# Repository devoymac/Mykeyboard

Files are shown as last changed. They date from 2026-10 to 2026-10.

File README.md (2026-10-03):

# Mykeyboard — Split Ergo Keyboard

Teclado ergonómico split de diseño propio. Proyecto de hardware abierto: esquemáticos y PCB en KiCad, firmware en QMK, y carcasa imprimible en 3D.

## Layout

Split columnar-stagger ISO-ES (español completo: Ñ, Ç, ‡, ¡, ¿), ~38 teclas por mitad, espacio dividido y flechas dedicadas.

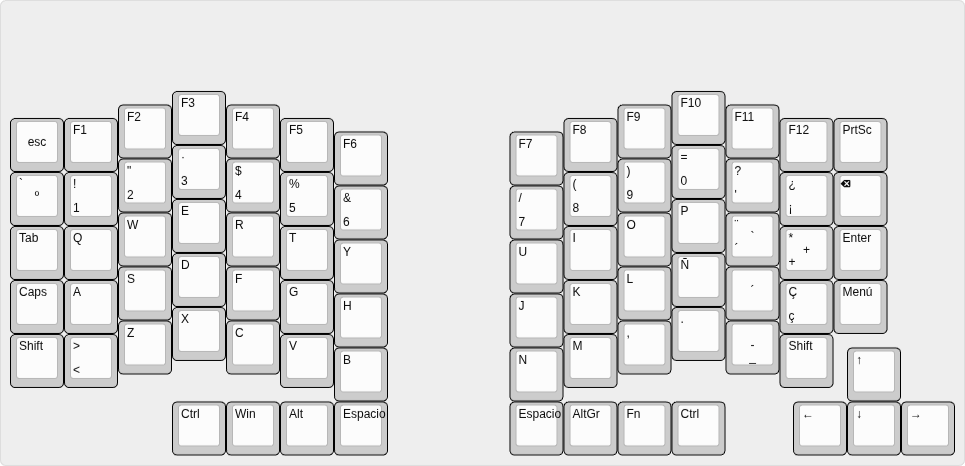
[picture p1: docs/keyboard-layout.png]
Layout del teclado


## Estado

En desarrollo. Estructura del proyecto montada, KiCad 10.0.6 instalado, requisitos y layout definidos.

## Estructura del proyecto

```
Mykeyboard/
├── hardware/          # Diseño electrónico (KiCad)
│   ├── left/          # Mitad izquierda (esquemático + PCB)
│   ├── right/         # Mitad derecha (espejo de la izquierda)
│   └── shared/        # Librerías, símbolos, footprints y plantillas comunes
├── firmware/          # Firmware del teclado (QMK)
├── case/              # Carcasa imprimible en 3D (STL / FreeCAD)
├── docs/              # Documentación: requisitos, layout, BOM, decisiones
├── tools/             # Scripts de utilidad (generación, automatización)
└── README.md
```

## Hardware

- **KiCad**: 10.0.6 (esquemático y PCB).
- **Layout**: split columnar-stagger ISO-ES, ~37-38 teclas por mitad, placa única que se parte en dos (V-cut/mouse bites).
- **Controlador**: RP2040-Zero por mitad, conectadas por TRRS.
- **Switches**: Outemu Silent Lemon V3 (táctiles silenciosos), soldados.
- **Pantalla**: OLED 128x32 (I2C) en la mitad izquierda.
- **Extras**: encoder rotatorio EC11 (volumen/medios) en la mitad derecha.
- Ver [docs/requirements.md](docs/requirements.md), [docs/layout.md](docs/layout.md) y el [BOM](docs/bom.md).

## Firmware

QMK (cableado).

## Cómo contribuir / desarrollo

1. Clona el repositorio.
2. Abre los proyectos de KiCad en `hardware/left` y `hardware/right`.
3. Documenta cualquier cambio relevante en `docs/`.

## Licencia

Pendiente de decidir (recomendado: CERN-OHL-S para hardware, MIT para firmware).

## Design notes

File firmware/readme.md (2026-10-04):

# Mykeyboard

Teclado ergonómico split (cableado) con QMK.

- **Layout:** ISO-ES, 81 teclas (39 izquierda + 42 derecha), columnar stagger
- **MCU:** 2× RP2040-Zero (uno por mitad), comunicación por TRRS
- **Mitad izquierda (master):** OLED 128x32 (I2C)
- **Mitad derecha (slave):** encoder EC11
- **Switches:** Outemu Silent Lemon V3 (soldados)

## Matriz (ambas mitades, misma asignación)

| | GPIO |
|---|---|
| Filas (row 0-5) | GP0, GP1, GP2, GP3, GP4, GP5 |
| Columnas (col 0-6) | GP6, GP7, GP8, GP9, GP10, GP11, GP12 |

## Pines por mitad

**Izquierda (master):**
- OLED: SDA=GP13, SCL=GP14
- TRRS: TX=GP26, RX=GP27

**Derecha (slave):**
- Encoder: A=GP13, B=GP14, SW=GP15
- TRRS: T=GP26, R1=GP27

## Compilar

```sh
qmk compile -kb mykeyboard -km default
```

## Mano (EE_HANDS)

Ambas mitades usan la misma matriz, así que la mano se fija por EEPROM:

```sh
qmk flash -kb mykeyboard -km default -bl uf2-split-left
qmk flash -kb mykeyboard -km default -bl uf2-split-right
```

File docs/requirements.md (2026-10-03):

# Requisitos del teclado

Objetivo: teclado ergonómico split de diseño propio. Requisitos recogidos del usuario (2026-10-02).

## Layout
- Split ergonómico en una sola placa (un solo PCB, un solo controlador por mitad).
- **74 teclas (37 por mitad, simétrico)**, TKL-split: todas las teclas del G513 Carbon menos el numpad. Incluye `/ * - +` (ya en el bloque principal).
- La placa se fabrica de una pieza y se parte en dos mitades (V-cut / mouse bites) tras la fabricación.
- **Navegación y flechas en capas** (PrtSc, ScrLk, Pause, Ins, Home, PgUp, Del, End, PgDn, flechas) — no físicas, se muestran en el OLED.
- Fila de números completa (1-9, 0).
- F1-F12.
- **Layout ISO-ES** completo: Ñ, tilde (´), diéresis (¨), ç/Ç, grave (`), circunflejo (^).
- Pendiente de definir: columnar stagger, thumb clusters, distribución tecla a tecla exacta.

## Teclas imprescindibles
- Tab
- Caps Lock (mayúsculas/minúsculas)
- Shift (izquierdo y derecho)
- Control / Ctrl (izquierdo y derecho)
- Tecla Windows
- Alt y Alt Gr
- Enter
- Borrar (Backspace)
- Flechas (las 4)
- Suprimir (Delete)
- Imprimir pantalla (PrtSc) — para capturas
- Ñ (imprescindible)

## Pantalla / Indicadores
- **OLED 128x32** (I2C) en la **mitad izquierda**. Muestra capa, mayúsculas, WPM, etc.
- Conecta por I2C (GND, VCC, SDA, SCL) — 2 pines GPIO + alimentación.

## Control de medios
- **Encoder rotatorio EC11** en la **mitad derecha**: girar = subir/bajar volumen, pulsar = pausar/continuar, y función "siguiente" (configurable en firmware).
- Conecta al RP2040-Zero por 2 pines (A/B de rotación) + 1 pin (pulsador).

## Conectividad
- **Cableado** (USB). Se descarta inalámbrico/Bluetooth (decisión 2026-10-02).
- **Sin hub USB** (decisión 2026-10-03): el teclado se conecta al PC por un solo USB-C, sin puerto extra para periféricos.

## Hardware elegido
- **Controlador**: RP2040-Zero (Waveshare) por mitad. Cableado, USB-C, 4 MB flash, 20 GPIO.
- **Switches**: Outemu Silent Lemon V3 (táctil silencioso), **soldados** (sin sockets hot-swap).
- **Firmware**: QMK.

## Implicaciones técnicas
- **Layout ISO**: la tecla Ñ define el layout ISO (Enter en forma de L, Ñ junto a la L). Afecta al diseño del PCB y a las keycaps.
- **PrtSc**: poco común en teclados custom; se puede poner como tecla física o en una capa (Fn).
- **Split**: cada mitad lleva su controlador (2 RP2040-Zero), conectadas por TRRS.
- **Sin batería**: al ser cableado, no hay que integrar LiPo ni carga.

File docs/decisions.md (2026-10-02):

# Decisiones de diseño

Registro de decisiones (ADR ligero). Cada entrada: contexto, decisión, alternativas descartadas.

## 2026-10-02 — Inicio del proyecto

- **Decisión**: Estructura del proyecto montada con hardware (KiCad), firmware, case y docs separados.
- **Contexto**: Proyecto nuevo de teclado ergonómico split.
- **Pendiente**: elegir layout, MCU, conexión entre mitades (TRRS vs inalámbrico), y firmware (QMK vs ZMK).

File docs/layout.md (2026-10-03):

# Layout del teclado

74 teclas totales = 37 por mitad (simétrico). Split ISO-ES, placa única que se parte en dos mitades.
El clúster de navegación (PrtSc, ScrLk, Pause, Ins, Home, PgUp, Del, End, PgDn) y las **flechas** van en **capas** y se muestran en el OLED.

## MITAD IZQUIERDA (37 teclas) — Master (RP2040-Zero + OLED + TRRS)

```
Fila F:     F1    F2    F3    F4    F5    F6
Números:    1     2     3     4     5     6
Top:        Q     W     E     R     T
Home:       A     S     D     F     G
Inferior:   Z     X     C     V     B
Modific.:   Tab   Caps  Shift Ctrl  Win   Alt
Pulgar:              [Espacio  AltGr  Fn  Menú]
```

Conteo: F(6) + Números(6) + Top(5) + Home(5) + Inferior(5) + Mod(6) + Pulgar(4) = 37

## MITAD DERECHA (37 teclas) — Slave (RP2040-Zero + encoder + TRRS)

```
Fila F:     F7    F8    F9    F10   F11   F12
Números:    7     8     9     0     -     =
Top:        Y     U     I     O     P
Home:       H     J     K     L     Ñ     ´     ç
Inferior:   N     M     ,     .     /
Modific.:   Enter Bcksp RShift RCtrl Menu  RAlt
Pulgar:              [Espacio   Fn]
```

Conteo: F(6) + Números(6) + Top(5) + Home(7) + Inferior(5) + Mod(6) + Pulgar(2) = 37

## Notas
- La **tilde (´)**, **ç**, **grave (`)**, **circunflejo (^)** y sus variantes Shift van en las teclas ISO-ES de la fila Top/Home derecha.
- El **AltGr** (para €, @, etc.) va en el pulgar o mod izquierdo.
- **PrtSc**, **ScrLk**, **Pause** y multimedia van en una capa FN.
- **Encoder rotatorio EC11** en la mitad derecha (volumen + pausa/continuar + siguiente).
- **OLED** en la mitad izquierda. Cada mitad lleva su RP2040-Zero y jack TRRS.
- El layout incluye el clúster de navegación (PrtSc, ScrLk, Pause, Ins, Home, PgUp, Del, End, PgDn) y las flechas. Sin numpad.

## Matriz (filas × columnas)
- 44 teclas por mitad = matriz de ~6 filas × 7 columnas = 13 pines GPIO por controlador (cabe en los 20 del RP2040-Zero).

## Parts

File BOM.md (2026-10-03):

# Mykeyboard — bill of materials

<!-- Generated by Half Life from project cmuqkjvz601uk01rlczve57yk. Edits here are overwritten on the next sync. -->
<!-- Generated: 2026-10-03T20:49:04.291Z -->

> [!NOTE]
> This parts list is mirrored from [Half Life](https://halflife.hackclub.com). Editing it here will not change the platform's copy, and the next sync overwrites this file.

| Week | Tier | Parts funding |
| --- | --- | --- |
| Warm-up | Tier 1 | $30.00 |

| Part | What it's for | Qty | Unit | Total | Vendor |
| --- | --- | --- | --- | --- | --- |
| [Outemu Silent Lemon V3 (tactile silent)](https://es.aliexpress.com/item/1005007805630498.html) | Switches - quiet tactile for office | 90 | $0.23 | $20.70 | [AliExpress](https://es.aliexpress.com/item/1005007805630498.html) |
| [RP2040-Zero](https://es.aliexpress.com/item/1005008603095009.html) | Microcontroller (one per half) | 2 | $1.74 | $3.48 | [AliExpress](https://es.aliexpress.com/item/1005008603095009.html) |
| [1N4148 diodes SMD (SOD-123)](https://www.aliexpress.com/item/4000470978915.html) | Matrix diodes (one per key) | 100 | $0.01 | $1.00 | [AliExpress](https://www.aliexpress.com/item/4000470978915.html) |
| [OLED 128x32 (0.91in I2C SSD1306)](https://www.aliexpress.com/item/32794209149.html) | Display on left half (I2C) | 1 | $1.12 | $1.12 | [AliExpress](https://www.aliexpress.com/item/32794209149.html) |
| [TRRS audio jack PJ-320A (3.5mm 4-pole)](https://www.aliexpress.com/item/33029465106.html) | Connect the two halves | 10 | $0.16 | $1.60 | [AliExpress](https://www.aliexpress.com/item/33029465106.html) |
| [EC11 rotary encoder (5-pin with push button)](https://www.aliexpress.com/item/32984027505.html) | Knob on right half (volume/media) | 2 | $0.96 | $1.92 | [AliExpress](https://www.aliexpress.com/item/32984027505.html) |
| **Parts subtotal** | — | — | — | **$29.82** | — |
| **Tax & shipping** | — | — | — | **$0.00** | — |
| **Total** | — | — | — | **$29.82** | — |

$0.18 left of the tier's funding.

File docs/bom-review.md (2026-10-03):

# BOM — Under $30 (review copy)

Build total: **~$29.51** (components, before shipping). This is the review version; the importable CSV is `bom.csv`.

## What's in it (in English)

| Item | Qty | Total (USD) | What it's for |
|---|-----|---|---|
| Outemu Silent Lemon V3 (tactile silent) | 90 | $20.37 | The quiet tactile switches you press (85 keys + 5 spare) |
| RP2040-Zero | 2 | $3.49 | Microcontroller — the "brain" of each half |
| 1N4148 diodes (SOD-123) | 100 | $0.97 | One per key, makes the key matrix work |
| OLED 128x32 (I2C SSD1306) | 1 | $1.12 | Screen on the left half (shows layer, caps, etc.) |
| TRRS jack PJ-320A (3.5mm 4-pole) | 10 | $1.64 | Connects the two halves together |
| EC11 rotary encoder (5-pin, push button) | 2 | $1.92 | Knob on right half (volume / play-pause) |
| **TOTAL** | | **$29.51** | |

## How to get it under $30

- Kept the **Outemu Silent Lemon V3** you want, bought **90** (you need 85: 39 left + 46 right).
- Kept all modules (RP2040-Zero, OLED, encoder use their own onboard parts — no extra caps/resistors).

## Link status — please review

- ✅ **RP2040-Zero** and **switches**: I opened these pages directly and verified the price live.
- ⚠️ **Diodes, OLED, TRRS**: links found from search (product IDs from listing databases) — open them to confirm they're live before ordering.
- ⚠️ **EC11 encoder**: link live (HTTP 200), price from a listing database (2 pcs ~$1.92). Open to confirm before ordering. Make sure it's 5-pin with a push button — the user's one at home isn't usable.

## Shipping note

To stay near $30 delivered, prefer sellers with **free shipping** and try to order the switches together with the diodes/jacks from the same store if possible. Separate sellers each add shipping (~$1–3 per order).

> CSV import target: using a generic format so it works in Google Sheets / Excel / Notion etc. Confirm which tool you're importing into if it needs something specific.

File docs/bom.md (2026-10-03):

# BOM — Lista de materiales

Teclado split ergonómico, placa única partida en dos mitades. Cantidades basadas en el layout (~38-45 teclas por mitad).

## Electrónica

> **USB-C**: se usa el puerto del propio RP2040-Zero de la mitad master (no hace falta receptáculo USB-C aparte ni resistencias CC). El cable del PC se enchufa directo al puerto del RP2040-Zero.

| Ref | Componente | Cant. | Notas |
|-----|---|---|---|
| U1, U2 | RP2040-Zero (Waveshare) | 2 | Uno por mitad. |
| SW | Outemu Silent Lemon V3 (táctil silencioso) | ~83 | Según layout; pedir lote de 90 o 110 para repuestos. |
| D1..Dn | Diodo 1N4148 (SMD SOD-123 o DO-35) | ~83 | Uno por tecla (matriz), no incluidas con switches. |
| J | OLED 128x32 (I2C) | 1 | Mitad izquierda. |
| RV1 | Encoder rotatorio EC11 + pulsador | 1 | Mitad derecha (volumen / pausa / siguiente). |
| J1, J2 | Jack audio 3.5mm TRRS (PJ-320A) | 2 | Conectan las mitades. |

> **Sin discretos**: al usar módulos RP2040-Zero (con su propio desacople) y módulos OLED/encoder, no hace falta añadir condensadores ni resistencias externas. Solo si el OLED diera problemas de I2C al probar, añadir 2 pull-ups (4.7kΩ).

## Mecánica / Otros

| Componente | Cant. | Notas |
|---|---|---|
| Cable TRRS 3.5mm | 1 | Une las dos mitades. |
| Cable USB-C | 1 | Al PC. |
| Keycaps | ~83 | Set ISO-ES completo (con Ñ, Ç, etc.). |
| Plate / carcasa (impresa o metal) | 1-2 | Placa superior para los switches. |
| Carcasa 3D (opcional) | 2 | Cases izquierdo/derecho. |
| Tornillos + insertos | ~ | Según carcasa. |

## Estimación de coste (componentes, sin keycaps)

- Controladores: ~4 € (2× RP2040-Zero)
- Switches: ~19 € (lote 90)
- Diodos: ~3 €
- OLED + encoder: ~6 €
- Jacks TRRS: ~2 €
- **Total electrónica: ~34 €** (sin keycaps ni carcasa)

> Las cantidades de teclas son orientativas; cuadrar con el layout definitivo en [docs/layout.md](layout.md).

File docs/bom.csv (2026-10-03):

Item | Qty | Unit Price (USD) | Total (USD) | Vendor | Link | Purpose | Link verified
Outemu Silent Lemon V3 (tactile silent) | 90 | 0.226 | 20.37 | AliExpress | https://es.aliexpress.com/item/1005007805630498.html | Switches - quiet tactile for office | Yes (90pcs = 18.69 EUR)
RP2040-Zero | 2 | 1.74 | 3.49 | AliExpress | https://es.aliexpress.com/item/1005008603095009.html | Microcontroller (one per half) | Yes (1.60 EUR each)
1N4148 diodes SMD (SOD-123) | 100 | 0.010 | 0.97 | AliExpress | https://www.aliexpress.com/item/4000470978915.html | Matrix diodes (one per key) | From search - check
OLED 128x32 (0.91in I2C SSD1306) | 1 | 1.12 | 1.12 | AliExpress | https://www.aliexpress.com/item/32794209149.html | Display on left half (I2C) | From search - check
TRRS audio jack PJ-320A (3.5mm 4-pole) | 10 | 0.164 | 1.64 | AliExpress | https://www.aliexpress.com/item/33029465106.html | Connect the two halves | From search - check
EC11 rotary encoder (5-pin with push button) | 2 | 0.96 | 1.92 | AliExpress | https://www.aliexpress.com/item/32984027505.html | Knob on right half (volume/media) | Live (HTTP 200)
TOTAL |  |  |  | 29.51

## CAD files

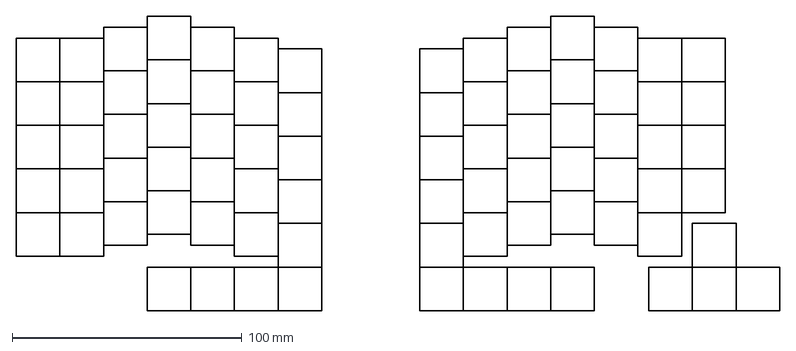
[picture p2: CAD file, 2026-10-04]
docs/demo.dxf
332.5 x 128.2 mm

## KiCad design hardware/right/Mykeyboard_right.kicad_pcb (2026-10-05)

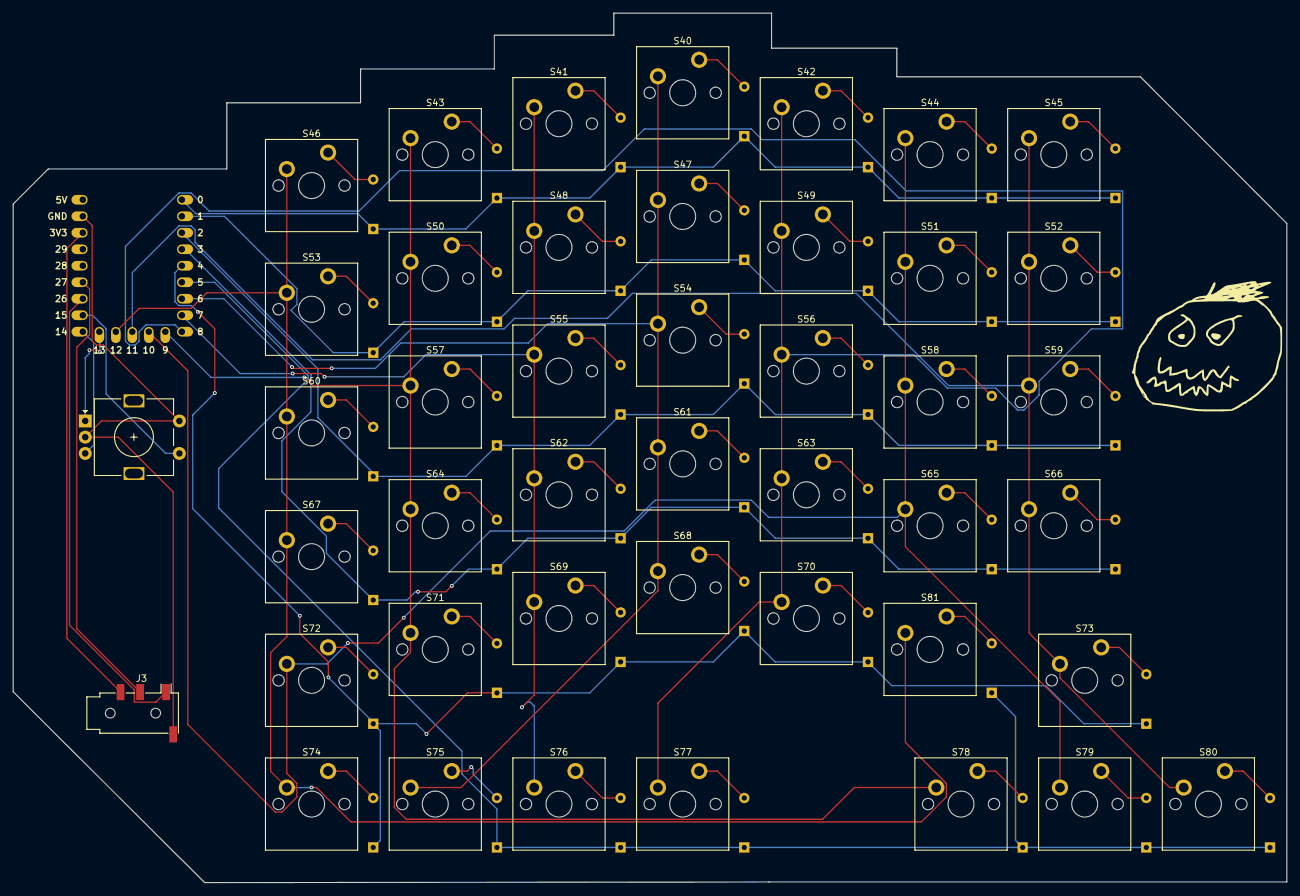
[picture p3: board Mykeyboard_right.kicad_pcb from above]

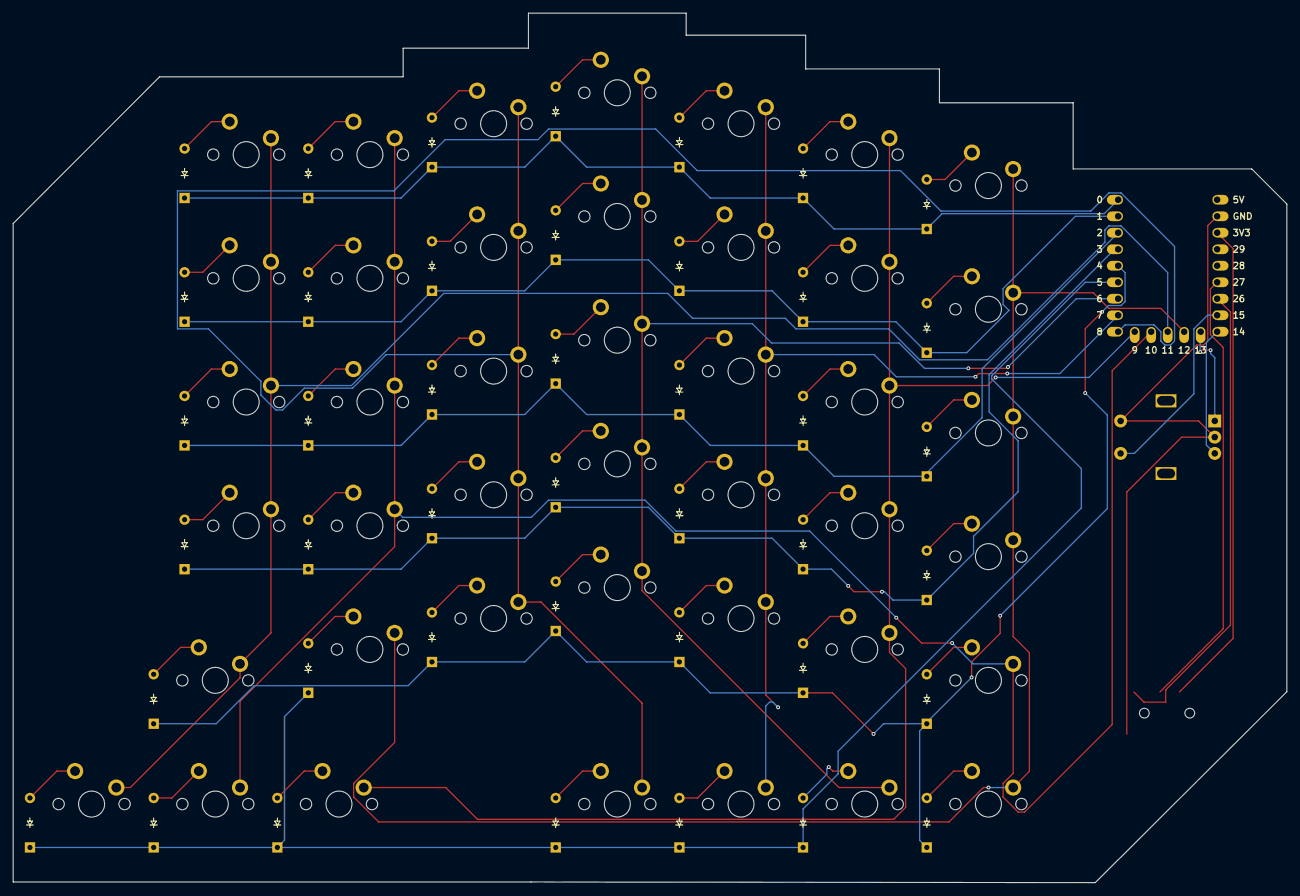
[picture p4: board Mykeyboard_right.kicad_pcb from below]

Board: 2 copper layers, 196.1 x 133.9 mm, 87 parts (42 on the bottom side), 62 nets.

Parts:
D40, D41, D42, D43, D44, D45, D46, D47, D48, D49, D50, D51, D52, D53, D54, D55, D56, D57, D58, D59, D60, D61, D62, D63, D64, D65, D66, D67, D68, D69, D70, D71, D72, D73, D74, D75, D76, D77, D78, D79, D80, D81: Diode_DO-35
J3: AudioJack4; Jack_3.5mm_PJ320D_Horizontal
S40, S41, S42, S43, S44, S45, S46, S47, S48, S49, S50, S51, S52, S53, S54, S55, S56, S57, S58, S59, S60, S61, S62, S63, S64, S65, S66, S67, S68, S69, S70, S71, S72, S73, S74, S75, S76, S77, S78, S79, S80, S81: MX_PCB_1.00u
SW1: RotaryEncoder_Switch; RotaryEncoder_Alps_EC11E-Switch_Vertical_H20mm
U2: RP2040_Zero

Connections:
/colum 7: S40.1, S47.1, S54.1, S61.1, S68.1, S75.1, U2.7 (6)
/colum 8: S41.1, S48.1, S55.1, S62.1, S69.1, S76.1, U2.8 (7)
/colum 9: S42.1, S49.1, S56.1, S63.1, S70.1, S77.1, U2.9 (8)
/colum 10: S43.1, S50.1, S57.1, S64.1, S71.1, S78.1, U2.10 (9)
/colum 11: S44.1, S51.1, S58.1, S65.1, S72.1, S79.1, U2.11 (10)
/colum 12: S45.1, S52.1, S59.1, S66.1, S73.1, S80.1, U2.12 (11)
/colum 13: S46.1, S53.1, S60.1, S67.1, S74.1, S81.1, U2.13 (12)
/row 6: D40.1 (K), D41.1 (K), D42.1 (K), D43.1 (K), D44.1 (K), D45.1 (K), D46.1 (K), U2.1 (0)
/row 7: D47.1 (K), D48.1 (K), D49.1 (K), D50.1 (K), D51.1 (K), D52.1 (K), D53.1 (K), U2.2 (1)
/row 8: D54.1 (K), D55.1 (K), D56.1 (K), D57.1 (K), D58.1 (K), D59.1 (K), D60.1 (K), U2.3 (2)
/row 9: D61.1 (K), D62.1 (K), D63.1 (K), D64.1 (K), D65.1 (K), D66.1 (K), D67.1 (K), U2.4 (3)
/row 10: D68.1 (K), D69.1 (K), D70.1 (K), D71.1 (K), D72.1 (K), D73.1 (K), D74.1 (K), U2.5 (4)
/row 11: D75.1 (K), D76.1 (K), D77.1 (K), D78.1 (K), D79.1 (K), D80.1 (K), D81.1 (K), U2.6 (5)
unnamed: D40.2 (A), S40.2
unnamed: D41.2 (A), S41.2
unnamed: D42.2 (A), S42.2
unnamed: D43.2 (A), S43.2
unnamed: D44.2 (A), S44.2
unnamed: D45.2 (A), S45.2
unnamed: D46.2 (A), S46.2
unnamed: D47.2 (A), S47.2
unnamed: D48.2 (A), S48.2
unnamed: D49.2 (A), S49.2
unnamed: D50.2 (A), S50.2
unnamed: D51.2 (A), S51.2
unnamed: D52.2 (A), S52.2
unnamed: D53.2 (A), S53.2
unnamed: D54.2 (A), S54.2
unnamed: D55.2 (A), S55.2
unnamed: D56.2 (A), S56.2
unnamed: D57.2 (A), S57.2
unnamed: D58.2 (A), S58.2
unnamed: D59.2 (A), S59.2
unnamed: D60.2 (A), S60.2
unnamed: D61.2 (A), S61.2
unnamed: D62.2 (A), S62.2
unnamed: D63.2 (A), S63.2
unnamed: D64.2 (A), S64.2
unnamed: D65.2 (A), S65.2
unnamed: D66.2 (A), S66.2
unnamed: D67.2 (A), S67.2
unnamed: D68.2 (A), S68.2
unnamed: D69.2 (A), S69.2
unnamed: D70.2 (A), S70.2
unnamed: D71.2 (A), S71.2
unnamed: D72.2 (A), S72.2
unnamed: D73.2 (A), S73.2
unnamed: D74.2 (A), S74.2
unnamed: D75.2 (A), S75.2
unnamed: D76.2 (A), S76.2
unnamed: D77.2 (A), S77.2
unnamed: D78.2 (A), S78.2
unnamed: D79.2 (A), S79.2
unnamed: D80.2 (A), S80.2
unnamed: D81.2 (A), S81.2
unnamed: J3.R2, U2.21 (3V3)
unnamed: SW1.A, U2.14 (13)
unnamed: SW1.B, U2.15 (14)
unnamed: SW1.S1, U2.16 (15)
unnamed: J3.T, U2.17 (26)
unnamed: J3.R1, U2.18 (27)
unnamed: J3.S, SW1.C, SW1.S2, U2.22 (GND)

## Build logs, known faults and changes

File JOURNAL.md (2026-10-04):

# Mykeyboard — devlog

<!-- Generated by Half Life from project cmuqkjvz601uk01rlczve57yk. Edits here are overwritten on the next sync. -->
<!-- Generated: 2026-10-04T21:28:46.204Z -->

> [!NOTE]
> This devlog is mirrored from [Half Life](https://halflife.hackclub.com). Editing it here will not change the platform's copy, and the next sync overwrites this file.

> An ergonomic keyboard for daily use

| Week | Tier | Hours logged | Entries |
| --- | --- | --- | --- |
| Warm-up | Tier 1 | 10h | 3 |

## Contents

1. [2026-10-03 — My split ergo keyboard p](#2026-10-03-imagehttpshalflifehackclub-assetscomhackclub-half)
2. [2026-10-04 — Hit a wall today, but figured it out. Turns out the layout I had originally was misplaced — the columns weren't lined up right, so it wasn't actually symmetric after all. That bugged me, so I redid th](#2026-10-04-hit-a-wall-today-but-figured-it-out-turns-out-the)
3. [2026-10-04 — In the end I decided to do it as two separate boards and then join them together. It took me a while to decide, but it makes total sense: each half with its own RP2040-Zero, and the two talk to each o](#2026-10-04-in-the-end-i-decided-to-do-it-as-two-separate-boa)

## Design

### 2026-10-03 — My split ergo keyboard p

**3h**

My split ergo keyboard project — how it's going

KiCad and the libraries

I set up KiCad 10.0.6 and realized I was missing the kicad-library package — the one that ships all the symbols and footprints. That's why I kept getting that "library table not found" error when I opened the libraries window. Once I installed it, everything clicked into place.

I also grabbed the ScottoKicad library (Joe Scotto's, the go-to for handwired keyboards)

Nailing down what I want

I figured out the design as I went and jotted it down in docs/requirements.md:

- Wired (USB), no wireless.
- Spanish ISO layout: Ñ, accent marks, ç/Ç, ¡, ¿, the whole set.
- No numpad (don't use it).
- One single PCB that I split into two halves afterwards (V-cut / mouse bites) so I only order one board from JLCPCB.
- 37+37 keys, symmetric.
- OLED 128x32 on the left + EC11 encoder on the right.
- 2× RP2040-Zero, using the USB-C that already comes on the board itself (no hubs or extra receptacles).

Hunting down components

- 90 switches Outemu Silent Lemon V3 (silent tactile, so I don't annoy everyone at home)
- 2 RP2040-Zero.
- OLED, encoder, TRRS jacks

The layout in KLE

I ended up designing the layout to my liking in Keyboard Layout Editor:

My layout


It's a split columnar-stagger in Spanish, ~37–45 keys per half, split spacebar, thumb clusters, and dedicated arrows on the right. Pretty happy with how it turned out.

The BOM and the repo

- Put together the BOM (docs/bom.md) with the full part list: ~€34 of electronics.
- Updated the README with the layout image and where the project stands.

My whole project is actually inspired by my main keyboard, the Logitech G513 Carbon — I've been using it for ages and it works great. But I wanted to take a simple step toward this new kind of keyboard, the ergonomic split, without leaving everything else behind.



### 2026-10-04 — Hit a wall today, but figured it out. Turns out the layout I had originally was misplaced — the columns weren't lined up right, so it wasn't actually symmetric after all. That bugged me, so I redid th

**4h**

Hit a wall today, but figured it out. Turns out the layout I had originally was misplaced — the columns weren't lined up right, so it wasn't actually symmetric after all. That bugged me, so I redid the whole thing from scratch.
And I actually got the whole schematic done! Switches + diodes matrix, both halves wired, the RP2040-Zero(s), the OLED, the TRRS jacks, and the encoder all placed and connected. Fixed the footprints as I went (diodes were wrongly grabbing the encoder footprint, etc.), sorted the "Update PCB from Schematic" thing, and dealt with the harmless mounting-pad warnings. Schematic is done and clean.

Now the new problem: I need to get this layout out of KLE and into the actual PCB. That's the part that's stressing me. I'm looking at either passing it to Ergogen (the web tool that generates the board for you) or finding some other way to convert it — and then I still have to figure out how to place all the switches in KiCad without dying of boredom doing it one by one.




### 2026-10-04 — In the end I decided to do it as two separate boards and then join them together. It took me a while to decide, but it makes total sense: each half with its own RP2040-Zero, and the two talk to each o

**3h**

In the end I decided to do it as two separate boards and then join them together. It took me a while to decide, but it makes total sense: each half with its own RP2040-Zero, and the two talk to each other over a TRRS cable. That way I don't have to order one giant board or cut it myself — each arm is its own board, easier to manufacture and to assemble.



And I finally got the wiring done. It's been the thing that took me the longest in this whole project, by far. The switch matrix with its diodes, the encoder on the right, the OLED on the left, the TRRS jacks... getting every pin to its right place and making the schematic coherent took a ton of back-and-forth. But it's done.

I also got the firmware framework set up in QMK: the split keyboard with its matrix, the encoder, the OLED, and the TRRS communication. It already compiles as RP2040.



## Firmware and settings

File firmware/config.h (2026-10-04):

// Copyright 2026 devoymac
// SPDX-License-Identifier: GPL-2.0-or-later

#pragma once

// Split: ambas mitades usan la misma matriz -> detección de mano por EEPROM
#define EE_HANDS

// Serial split (TRRS): TX=GP26, RX=GP27
#define SERIAL_USART_FULL_DUPLEX
#define SERIAL_USART_TX_PIN GP26
#define SERIAL_USART_RX_PIN GP27

// OLED (mitad izquierda, I2C): SDA=GP13, SCL=GP14
#define I2C_DRIVER I2CD1
#define I2C1_SDA_PIN GP13
#define I2C1_SCL_PIN GP14

// RP2040
#define RP2040_BOOTLOADER_DOUBLE_TAP_RESET
#define RP2040_BOOTLOADER_DOUBLE_TAP_RESET_TIMEOUT 500U

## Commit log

2026-10-02 Monta estructura del proyecto de teclado split ergonómico (hardware, firmware, case, docs)
2026-10-02 Preserva estructura de directorios con .gitkeep
2026-10-02 Documenta librería ScottoKicad y su licencia en el README
2026-10-02 Elimina submódulo ScottoKicad y toda referencia a la librería
2026-10-03 Añade requisitos del teclado (layout, pantalla, dual BT+cable, hub USB)
2026-10-03 Simplifica requisitos: teclado cableado con puerto USB (se descarta inalámbrico)
2026-10-03 Clarifica requisito: hub USB integrado para conectar periféricos
2026-10-03 Registra teclas imprescindibles y hardware elegido (RP2040-Zero, OLED 128x32, switches soldados, layout ISO)
2026-10-03 Sustituye OLED por LEDs indicadores de capa para reducir costes
2026-10-03 Crea proyecto KiCad (left) con esquemático inicial: RP2040-Zero, TRRS, hub USB y plantilla de matriz
    [left.kicad_sch]
2026-10-03 Elimina proyecto KiCad generado automáticamente (el diseño se hará manualmente)
    [left.kicad_sch]
2026-10-03 Fija layout TKL 87 teclas en una sola placa, ISO-ES con teclas de acentuación
2026-10-03 Recupera pantalla OLED 128x32 en lugar de LEDs de capa
2026-10-03 Añade layout 44 teclas/mano (88 total) y cuadrícula de referencia
2026-10-03 Añade encoder rotatorio EC11 para volumen/medios y confirma clúster de navegación
2026-10-03 Añade imagen del layout al README y crea el BOM
2026-10-03 Quita botón reset del BOM (el RP2040-Zero ya lo tiene en placa)
2026-10-03 Quita hub USB; OLED a la izquierda y encoder a la derecha
2026-10-03 BOM: usa USB-C del RP2040-Zero, quita receptáculo y resistencias CC
2026-10-03 BOM: sin condensadores/resistencias externas (se usan módulos)
2026-10-03 Añade BOM bajo $30 (CSV importable + nota de revisión)
    [bom.csv]
2026-10-03 Añade encoder EC11 al BOM (total $29.51)
    [bom.csv]
2026-10-03 Añade proyecto KiCad (Mykeyboard) e ignora .lck y .history
    [Mykeyboard.kicad_pcb, Mykeyboard.kicad_sch]
2026-10-04 Añade framework QMK split (mykeyboard): matriz, encoder, OLED, TRRS
2026-10-04 Divide hardware en mitades left/right, mueve framework QMK a firmware/, añade docs
    [Mykeyboard.kicad_pcb, Mykeyboard_left.kicad_pcb, Mykeyboard_left.kicad_sch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]
2026-10-04 Corrige framework QMK: layout split completo, split.matrix_pins.right, diode_direction, keymap intercalado (compila)
2026-10-05 little details
    [Mykeyboard_right.kicad_pcb]
